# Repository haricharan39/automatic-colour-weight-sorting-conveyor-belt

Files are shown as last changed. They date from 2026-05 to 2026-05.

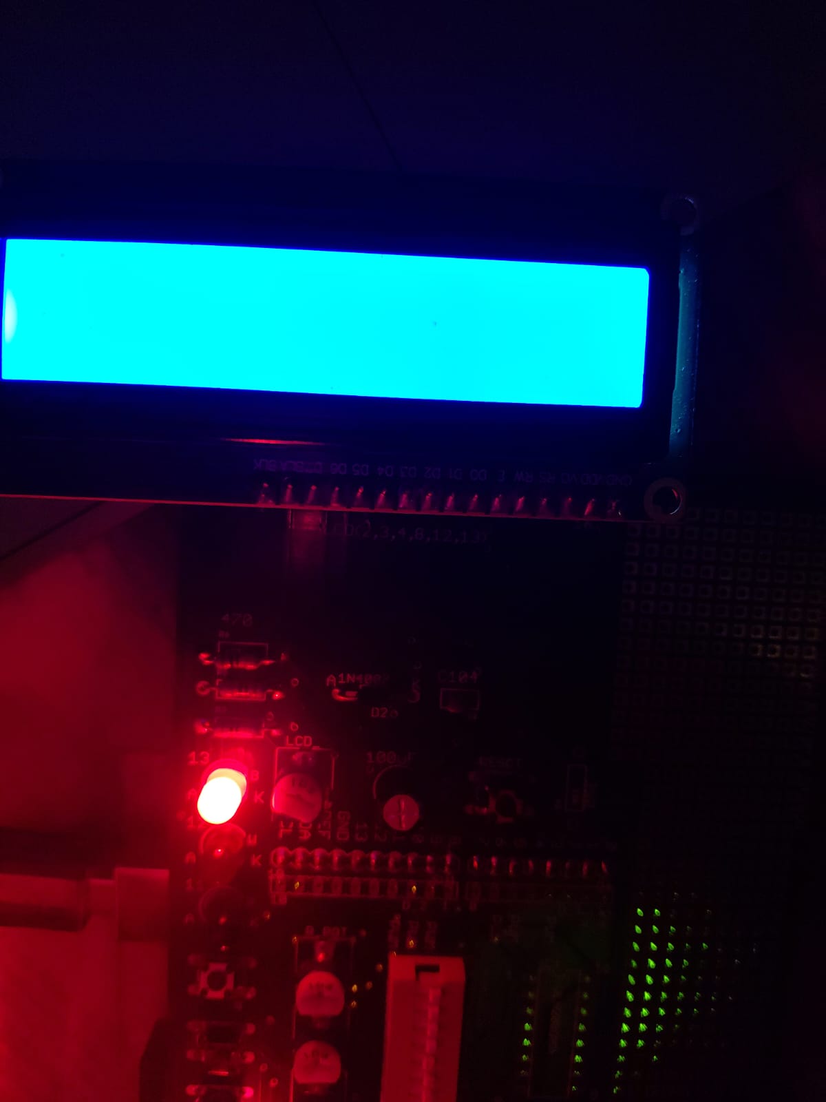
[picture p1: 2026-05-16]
Images/WhatsApp Image 2026-05-16 at 15.00.31.jpeg

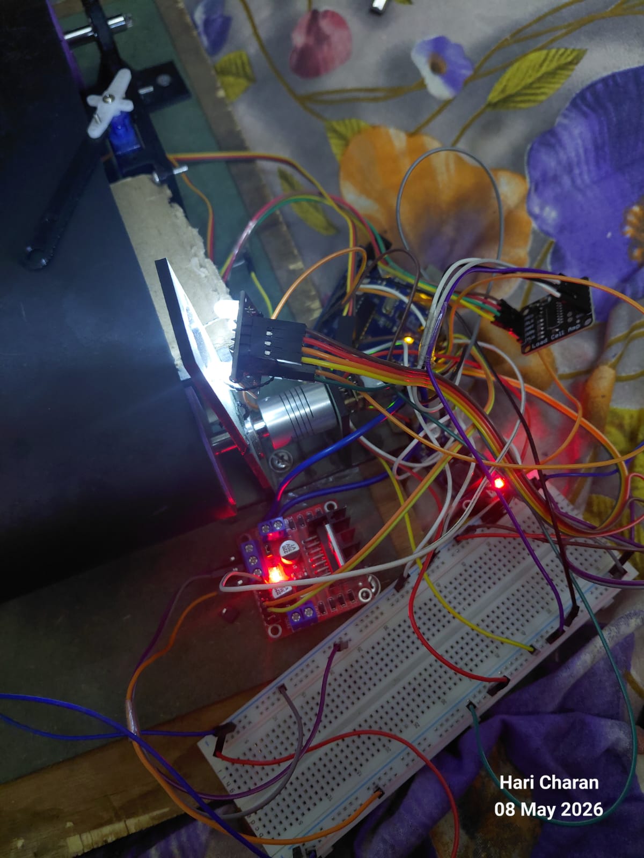
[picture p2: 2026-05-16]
Images/WhatsApp Image 2026-05-16 at 14.24.29 (3).jpeg

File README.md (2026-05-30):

# Automatic-Colour-Weight-Sorting-Conveyor-Belt

## Introduction

The Automatic Colour and Weight Sorting Conveyor Belt project is an Arduino-based automation system designed to identify and separate objects based on their colour and weight. The system uses sensors, a conveyor mechanism, and servo-controlled sorting techniques to automate the sorting process efficiently. This project demonstrates the practical application of automation, embedded systems, and sensor integration in industrial material handling and smart manufacturing systems.

## Objective

The objective of this project was to design and develop an automated conveyor belt system capable of sorting objects based on their colour and weight using sensors and microcontroller-based control systems. 

The project aimed to understand automation principles, sensor integration, object detection, and industrial sorting mechanisms through practical implementation.

## Components Used

* Arduino UNO
* Conveyor belt mechanism
* Servo motors
* Colour sensor
* Load cell sensor
* HX711 load cell amplifier
* IR sensors
* LCD display
* DC motor
* Motor driver module
* Power supply
* Connecting wires and supporting frame
* Cardboard
* Colours
* GI Sheets
* 3-D Printed Stuff

## Working Principle

The conveyor belt continuously moves objects through the sensing area. Firstly IR Detects the Object and the colour sensor detects the colour of the object, while the load cell measures its weight. The Arduino processes the sensor data and determines the appropriate category for the object.

Based on the detected parameters, servo motors are activated to divert the object into the correct collection section. The LCD display shows real-time information such as detected colour and measured weight during operation.

## Design and Implementation

The project was designed using a conveyor mechanism integrated with multiple sensors and servo-controlled sorting sections. The Arduino UNO acted as the main controller for processing sensor data and controlling the conveyor operation.

The load cell and colour sensor were calibrated carefully to improve measurement accuracy. Servo motors were positioned strategically to guide objects into separate sections based on predefined sorting conditions. The system was tested repeatedly to ensure smooth conveyor movement and accurate object classification.

## Engineering Concepts Applied

* Industrial automation
* Embedded systems
* Sensor integration
* Object detection and classification
* Conveyor mechanism design
* Control systems
* Microcontroller programming
* Mechatronics and automation

## Problems Faced

Several challenges were encountered during the development of the project. Sensor readings initially showed fluctuations and inconsistent values, affecting sorting accuracy. Conveyor movement also faced alignment and speed control issues during testing.

The servo motors occasionally responded with delays due to improper timing and synchronization with the conveyor system. Wiring management and sensor calibration required multiple adjustments to achieve stable operation.

## Solutions Implemented

Sensor calibration was performed multiple times to improve the accuracy and consistency of colour and weight detection. Noise reduction techniques and stable power connections helped minimize fluctuations in sensor readings.

The conveyor alignment was corrected to ensure smooth movement of objects without slipping or blockage. Motor speed adjustments were made to maintain proper synchronization between sensing and sorting operations.

Servo control timing was optimized in the Arduino program to achieve accurate object diversion at the correct moment. Wiring connections were organized carefully to improve reliability and reduce signal disturbances during operation and for load cell amplifier the soldering is not done efficiently so that the noise or voltage difference changes continuously so that the weight is not accurate and stable it is observed lately and corrected in no time....

## Testing and Results

The conveyor belt system was tested using objects with different colours and weights to evaluate sorting accuracy and system performance. During testing, the sensors successfully identified the object properties, and the servo motors sorted the objects into their respective sections.

The conveyor operated smoothly under continuous operation, and the overall system achieved reliable sorting performance with minimal errors. The project successfully demonstrated automated object detection, classification, and sorting using sensor-based control systems.

## Key Learnings

This project provided practical exposure to industrial automation systems and embedded control mechanisms. It improved understanding of sensor calibration, microcontroller programming, conveyor system design, and actuator control.

The project also demonstrated the importance of synchronization, accurate sensing, and system integration in automation-based applications. Valuable experience was gained in troubleshooting hardware issues, optimizing control logic, and improving system reliability through repeated testing.

## Future Improvements

The project can be improved further by integrating advanced sensors and machine vision systems for more accurate object detection and classification. Wireless monitoring and IoT-based control can also be implemented for remote operation and data analysis.

The conveyor system can be expanded to support higher-speed industrial applications with larger sorting capacities. Artificial intelligence and machine learning techniques may also be integrated in future versions to improve sorting accuracy and enable intelligent automation.

## Conclusion

The Automatic Colour and Weight Sorting Conveyor Belt project successfully demonstrated the implementation of automation and sensor-based sorting techniques using an Arduino-controlled system. The project achieved reliable object detection, classification, and sorting through the integration of sensors, actuators, and embedded programming.

The project provided valuable practical experience in automation, mechatronics, and industrial system design while highlighting the importance of precision, synchronization, and efficient control mechanisms in modern automated systems.

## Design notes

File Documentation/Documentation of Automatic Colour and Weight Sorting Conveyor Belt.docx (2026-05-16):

# Automated Conveyor Sorting System

# Introduction

Automation plays an important role in modern industries to increase efficiency and decrease manual effort. The conveyor system is used in most of the industries for transporting objects from one place to another. In some cases the objects need to be classified based on some characteristics such as colour or weight.

This project presents the design and development of a small automated conveyor system that detects the colour and weight of objects and sorts them into different bins. The system uses sensors and a microcontroller to perform the sorting operation automatically.

The goal of this project is to demonstrate the basic concept of industrial automation using simple Mechanical and electronic components.

# Objective

The main objective of project is to design and develop an Automated Conveyor Sorting System that can detect, analyze and sort objects based on their physical properties like colour and weight using sensors and microcontroller

This project aims to integrate various components like a colour sensor,load cell,IR sensor,DC motor and servo motors with an Arduino to create a real-time sorting mechanism.

↪️Specific Objectives

- To detect the presence of objects using an IR sensor
- To measure the weight of objects using a load cell with HX711 amplifier
- To identify the color of objects using a TCS3200 colour sensor
- To control conveyor movement using a DC motor and motor driver (L298N)
- To sort objects into different categories using servo motors
- To develop a complete system using Arduino UNO for control and processing

Components Used :

- Arduino UNO
- L298N Motor Driver
- Buck Converter (LM2596)
- DC Motor
- Servo Motors (2 units)
- IR Sensor
- TCS3200 Colour Sensor
- Load Cell
- HX711 Load Cell Amplifier
- Breadboard
- 12V Power Supply
- Connecting Wires
- 3D Printed Rollers
- Bearings
- Shaft Rod
- MDF Board
- Bread Board
- Rubber Sheet
- 3D Printed Servo Arms

WORKING PRINCIPLE

The automated conveyor sorting system operates by combining the functions of sensors, actuators, and a microcontroller to perform sorting of objects in a systematic manner.

Initially, the conveyor belt is driven by a DC motor, which provides continuous motion to transport objects from one end to another. When an object is placed on the moving conveyor belt, it starts traveling towards the sensing section of the system.

As the object reaches the sensing area, the IR sensor detects the presence of the object and sends a signal to the Arduino.

This detection ensures that the system begins analyzing the object at the correct position. Once the object is detected, the conveyor may momentarily slow down or continue moving steadily while the sensing process takes place.

The load cell placed beneath the sensing platform measures the weight of the object. The small electrical signal generated by the load cell is amplified and converted into digital data using the HX711 amplifier module, which is then read by the Arduino.

Simultaneously, the colour sensor (TCS3200) detects the color of the object by analyzing the light reflected from its surface. The sensor converts the color information into frequency signals, which are processed by the Arduino to determine the specific color of the object.

Based on the combined input from the weight measurement and color detection, the Arduino processes the data and classifies the object into a specific category. After classification, the conveyor continues to move the object towards the sorting section.

At the sorting point, the servo motor rotates its servo arm to a specific angle depending on the category of the object. This movement pushes the object into the appropriate bin or path assigned for that category.

This entire process is repeated continuously for every object placed on the conveyor belt, resulting in an efficient, accurate, and automated sorting system without the need for manual intervention.

Circuit Diagram

The circuit diagram of the automated conveyor sorting system is shown above. It illustrates the connections between the Arduino, sensors, motor driver, and power supply.

All components are connected through a common ground. The buck converter is used to provide a regulated 5V supply to the Arduino and sensors, while the motor driver is powered separately using a 12V supply.

The diagram clearly represents the interfacing of the colour sensor, IR sensor, load cell with HX711 module, servo motors, and DC motor with the Arduino.

Click Here (https://drive.google.com/file/d/1zyDLpXdCb_QY4AlogtuuWgVXAKq44nxD/view?usp=drivesdk) for the Circuit Diagram.

CONNECTIONS

The connections of the automated conveyor sorting system are made by interfacing all components with the Arduino and providing proper power supply through a buck converter and motor driver.

The 12V power supply is given to the L298N motor driver to drive the DC motor. The same 12V supply is also provided to the input of the buck converter.

The buck converter steps down the voltage to 5V, which is used to power the Arduino, sensors, and servo motors.

The DC motor is connected to the output terminals of the L298N motor driver. The control pins IN1 and IN2 of the motor driver are connected to the digital pins of the Arduino to control the direction of the motor.

The two servo motors are connected to the Arduino through digital pins, while their power is supplied from the 5V output of the buck converter. The IR sensor is connected to the Arduino to detect the presence of objects.

The colour sensor is connected to multiple digital pins of the Arduino for color detection, and its output pin is used to send frequency signals to the Arduino. The load cell is connected to the HX711 amplifier module, which is then connected to the Arduino for weight measurement.

All the ground connections of the components are made common to ensure proper functioning of the system.

DETAILED COMPONENT DESCRIPTION

↪️ Arduino UNO

- The Arduino UNO is the main controller of the system. It processes inputs from sensors and controls outputs like motors and servos.

Pins Used:

- 5V → Power input from buck converter
- GND → Common ground
- D2 → IR sensor output
- D3, D5 → L298N motor driver inputs
- D4, D6 → Servo motors
- D7–D10 → Colour sensor (S0–S3)
- D11 → Colour sensor OUT
- D12 → HX711 DT
- D13 → HX711 CLK

Use:

- Acts as the brain of the system.

↪️ L298N Motor Driver

- Used to control the DC motor and drive the conveyor.

Pins:

- 12V → Connected to 12V supply
- GND → Common ground
- 5V → Logic supply (from buck)
- IN1, IN2 → Connected to Arduino (D3, D5)
- OUT1, OUT2 → Connected to DC motor

Use:

- Controls motor direction and movement.

↪️ Buck Converter (LM2596)

- Used to step down voltage from 12V to 5V.

Pins:

- IN+ → 12V positive
- IN− → Ground
- OUT+ → 5V output
- OUT− → Ground

Use:

- Provides stable 5V to Arduino, sensors, and servos.

↪️ DC Motor

- Drives the conveyor belt.

Connection:

- Connected to OUT1 and OUT2 of L298N

Use:

- Moves objects on conveyor.

↪️Servo Motors (2)

- Used to sort objects.

Pins:

- Red → 5V
- Brown → GND
- Orange → Signal (D4, D6)

Use:

- Push objects into bins using a servo arm.

↪️ IR Sensor

- Detects presence of object.

Pins:

- VCC → 5V
- GND → GND
- OUT → Arduino D2

Use:

- Triggers detection when an object arrives.

↪️Colour Sensor (TCS3200)

Pins:

- VCC → 5V
- GND → GND
- S0 → D7
- S1 → D8
- S2 → D9
- S3 → D10
- OUT → D11
- OE → GND

Use:

- Detects color of object.

↪️ Load Cell

Wires:

- Red → E+
- Black → E−
- Green → A+
- White → A−

Use:

- Measures weight of object.

↪️ HX711 Amplifier

Pins:

- VCC / VDD → 5V
- GND → GND
- DT → D12
- CLK → D13
- A+, A− → Load cell
- E+, E− → Load cell

Use:

- Amplifies and converts load cell signal.

↪️ Breadboard

Use:

- Distributes 5V and GND
- Organizes connections

Connection:

- Buck OUT+ → 5V rail
- Buck OUT− → GND rail

↪️ Power Supply (12V)

Connection:

- 12V → L298N motor driver
- 12V → Buck converter input

Use:

- Provides main power for the system.

APPLICATIONS

- Industrial product sorting systems
- Packaging and assembly lines
- Waste segregation systems
- Food processing industries
- Recycling plants
- Smart manufacturing systems

Problems Faced During the Project

1. Unstable Load Cell Readings

One of the major challenges faced during the project. was obtaining stable and accurate readings from the load cell. Since the load cell produces very small analog signals, the readings were highly sensitive to vibrations, electrical noise, and loose wiring connections. Initially, the measured values fluctuated continuously and sometimes displayed zero even when weight was applied. This issue became more noticeable when the conveyor motor and servo motors were operating simultaneously.

To reduce this problem, multiple software filtering techniques such as averaging and stabilization delays were implemented. The HX711 module was also powered using 3.3V instead of 5V to reduce electrical noise. Additionally, the wiring connections were improved and secured properly.

2. Electrical Noise from Motor and Servos

The DC motor and servo motors generated electrical noise and electromagnetic interference (EMI), which affected the HX711 load cell amplifier. Whenever the conveyor motor stopped or the servos moved, unstable weight readings were observed. The noise also caused sudden fluctuations in sensor outputs.

To overcome this issue, delay intervals were introduced after stopping the motor so that vibrations and electrical disturbances could settle before taking weight measurements. Servo motors were also detached after movement to minimize PWM interference during weight sensing.

3. Incorrect Color Detection

The TCS3200 color sensor initially produced inconsistent color outputs. In several cases, the sensor repeatedly detected the same color even when different colored objects were placed in front of it. Environmental lighting conditions and improper sensor distance also affected the readings.

To improve color detection accuracy, multiple pulse readings were averaged and threshold comparisons were adjusted experimentally. Proper object placement and controlled lighting conditions helped achieve more reliable RGB detection.

4. Servo Motor Stability Issues

The SG90 servo motors did not hold angles firmly and occasionally showed jittering or shaking movements. This mainly occurred due to insufficient power supply and continuous PWM corrections by the servos. The shaking affected the sorting mechanism and caused inaccurate object sweeping.

Instead of using a locking mechanism, a sweeping mechanism was designed in which the servo quickly pushes the object into the required bin and returns to its home position. This reduced the load on the servos and improved overall reliability.

5. Conveyor Belt Alignment Problems

Maintaining proper conveyor belt alignment was another challenge during the mechanical assembly. Improper roller alignment caused uneven belt movement and occasional slipping of objects during transportation. The belt tension also had to be adjusted carefully to ensure smooth operation.

To solve this issue, roller supports and shaft supporters were redesigned and aligned properly. The mechanical structure was strengthened to improve stability during continuous operation.

6. Integration of Multiple Components

Integrating all hardware components into one synchronized system was a challenging task. Individual modules such as the load cell, color sensor, servo motors, and LCD worked correctly when tested separately, but issues appeared when all modules operated together simultaneously.

Careful timing control, sequencing of operations, and debugging were required to achieve stable integration. Delays were introduced between sensing and actuation stages to ensure proper synchronization between hardware and software operations.

7. Calibration Difficulties

The calibration factor of the load cell changed after modifying the power supply configuration and integrating the system with other components. Accurate weight measurement required repeated calibration trials using known weights.

Several experimental tests were conducted to determine a suitable calibration factor and weight threshold for differentiating HIGH and LOW weight objects accurately.

8. Timing and Synchronization Challenges

Proper coordination between conveyor movement, IR detection, color sensing, weight measurement, and servo actuation was critical for smooth operation. Incorrect timing caused premature sensing or inaccurate sorting.

To solve this issue, the complete workflow was redesigned with proper sequencing:

1. Conveyor motor runs
2. IR sensor detects object
3. Motor stops
4. Object stabilizes
5. Color and weight are measured
6. Servo performs sorting action

CONCLUSION

The automated conveyor sorting system successfully demonstrates the integration of sensors, actuators, and a microcontroller to perform sorting operations efficiently. The system is capable of detecting objects, analyzing their weight and color, and sorting them automatically without manual intervention.

This project highlights the practical application of embedded systems in automation and industrial processes. It can be further improved by increasing accuracy, adding more sensors, or implementing advanced control techniques.

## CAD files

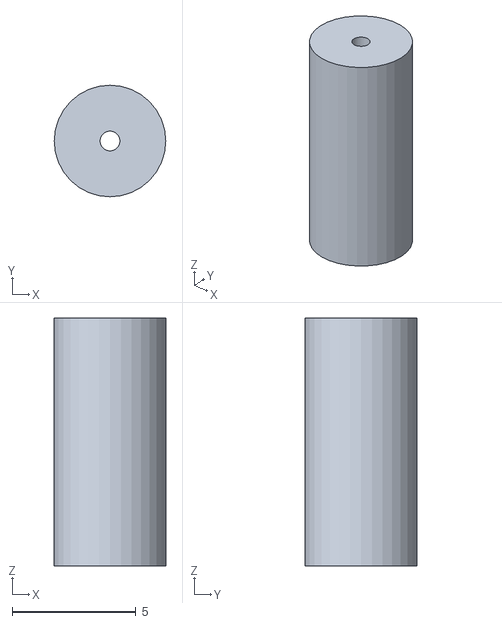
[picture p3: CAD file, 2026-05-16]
AutoCad Design/Roller.stl
4.50 x 4.50 x 10.0

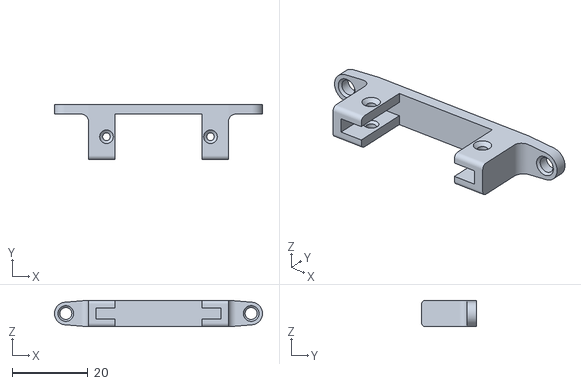
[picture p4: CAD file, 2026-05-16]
AutoCad Design/Servo Mounter.stl
55.0 x 14.5 x 7.00

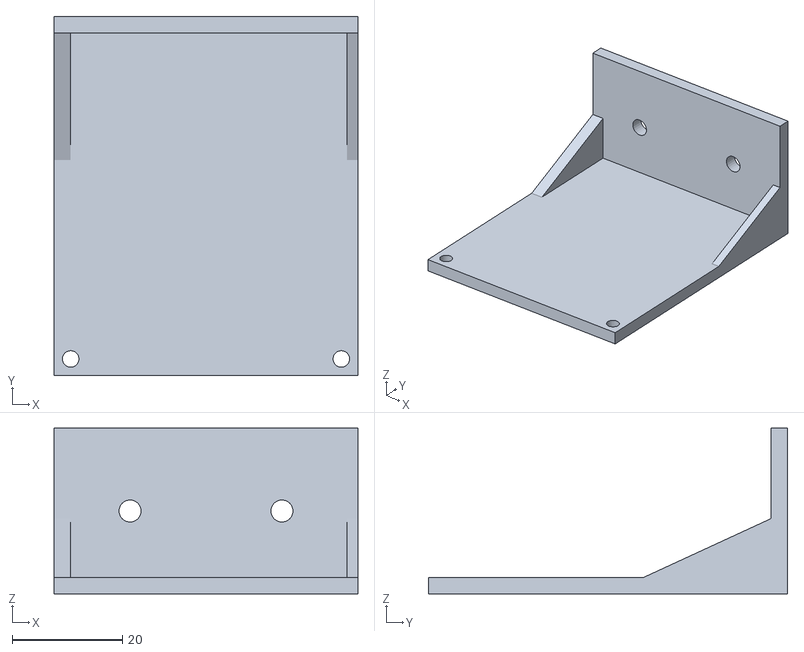
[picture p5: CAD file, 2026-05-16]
AutoCad Design/Servo Bracket.stl
55.0 x 65.0 x 30.0

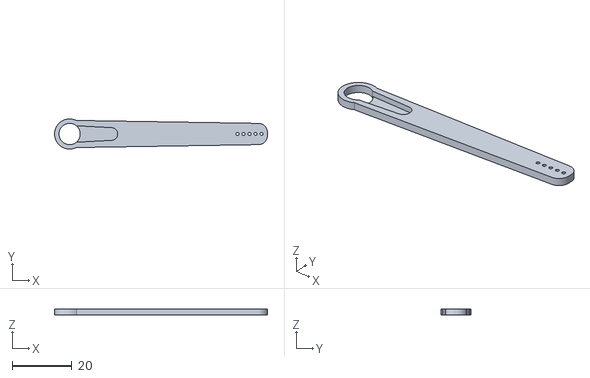
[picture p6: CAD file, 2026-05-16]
AutoCad Design/Servo Paddle.STL
71.1 x 10.1 x 2.00

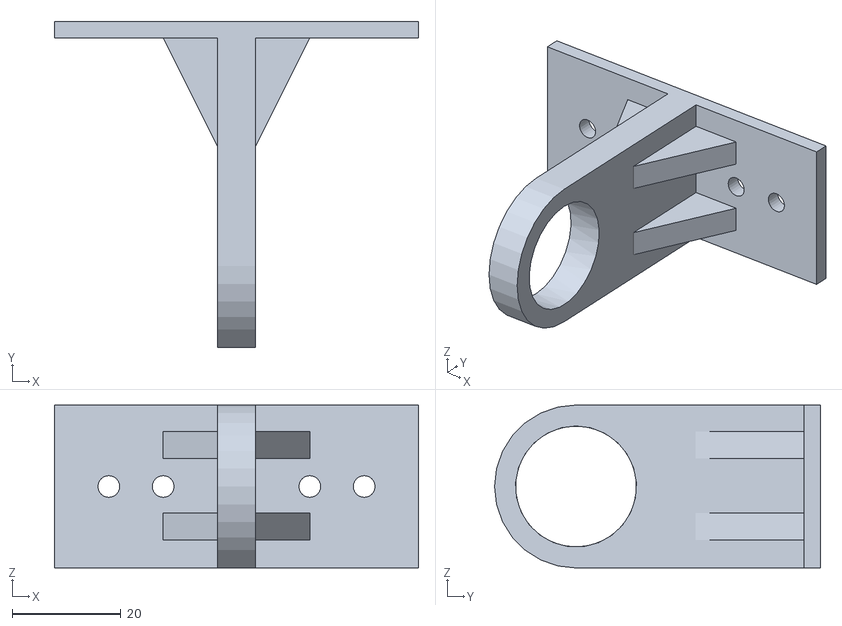
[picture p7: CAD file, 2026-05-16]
AutoCad Design/L-brackets supporter.stl
67.0 x 60.0 x 30.0

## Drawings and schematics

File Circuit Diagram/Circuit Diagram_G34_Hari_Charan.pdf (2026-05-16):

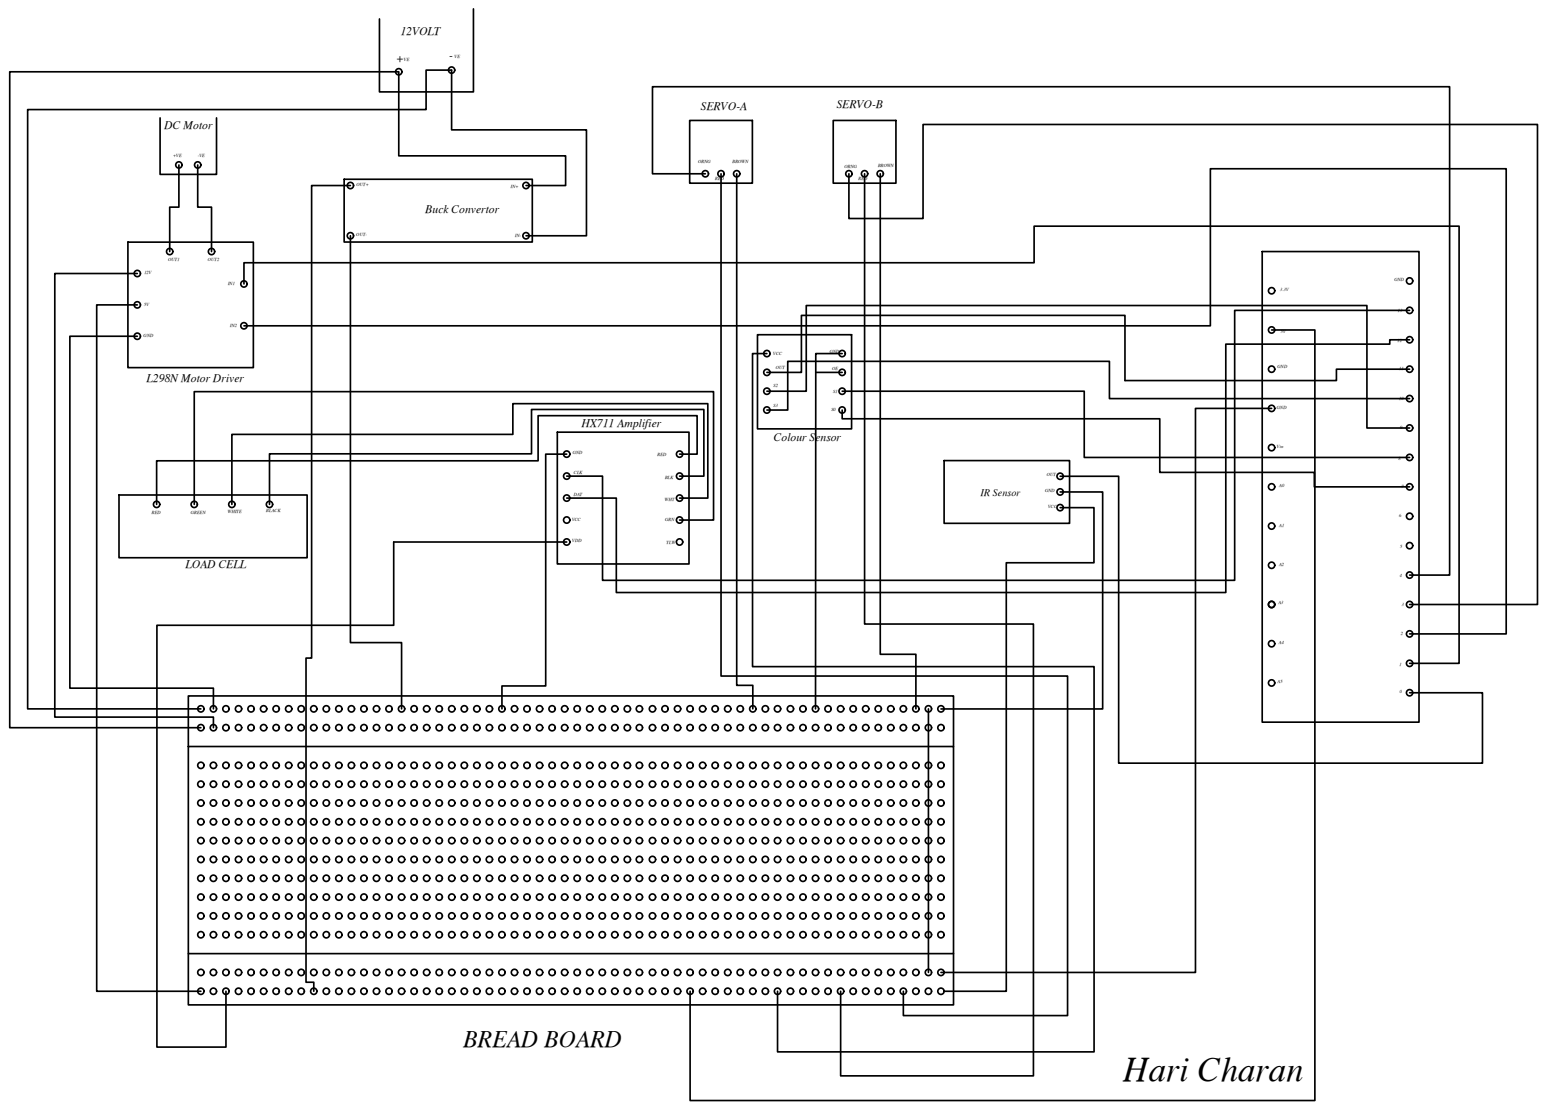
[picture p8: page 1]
Buck Convertor; Colour Sensor HX711 Amplifier L298N Motor Driver DC Motor; IR Sensor LOAD CELL; BREAD BOARD; SERVO-A; SERVO-B +; - 12VOLT; IN+IN- OUT+ OUT- 12V 5VGND; IN1IN2 OUT1; OUT2 RED; GREEN; WHITE; BLACK; GND CLK DAT VCC VDD; REDBLK WHT GRN YLW; VCCOUT S2S3; S0S1 OE GND; OUT GNDVCC ORNG RED; BROWN; RED ORNG; BROWN +VE; 01234567891011 1213 GND 3.3V 5V GND GND VinA0A1 A2 A3A4 A5 Hari Charan

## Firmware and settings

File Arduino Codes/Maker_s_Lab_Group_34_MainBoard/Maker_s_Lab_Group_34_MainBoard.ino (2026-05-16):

#include <Servo.h>
#include "HX711.h"
#define DOUT_PIN      3
#define CLK_PIN       2
#define S0_PIN        4
#define S1_PIN        5
#define S2_PIN        6
#define S3_PIN        7
#define COLOR_OUT_PIN 8
#define IR_PIN        9
#define ENA_PIN       10
#define IN1_PIN       12
#define IN2_PIN       11
#define SERVO_A_PIN   A0
#define SERVO_B_PIN   A1
const float FACTOR       = 1837.5;
const float WEIGHT_HIGH  = 36;
const float NOISE_FLOOR  = 3.0;
const int   MOTOR_SPEED  = 255;
const long  IR_TIMEOUT   = 45000;
const int  COLOR_GAP     = 20;
const long PULSE_TIMEOUT = 200000;
HX711 scale;
Servo servoA;
Servo servoB;
float finalWeight   = 0.0;
byte  detectedColor = 0;
void sendWaiting() {
  Serial.println(F("STATUS:WAIT"));
}
void sendReady() {
  Serial.println(F("STATUS:READY"));
}
void sendToDisplay(float weight, byte color) {
  String wLabel = (weight >= WEIGHT_HIGH) ? "HIGH" : "LOW";
  String cLabel;
  if      (color == 1) cLabel = "Red";
  else if (color == 3) cLabel = "Blue";
  else                 cLabel = "Unknown";
  Serial.print(F("W:"));
  Serial.print(wLabel);
  Serial.print(F(",C:"));
  Serial.println(cLabel);
}
void setup() {
  Serial.begin(9600);
  pinMode(ENA_PIN, OUTPUT);
  pinMode(IN1_PIN, OUTPUT);
  pinMode(IN2_PIN, OUTPUT);
  digitalWrite(IN1_PIN, LOW);
  digitalWrite(IN2_PIN, LOW);
  analogWrite(ENA_PIN, 0);
  pinMode(IR_PIN, INPUT);
  pinMode(S0_PIN, OUTPUT);
  pinMode(S1_PIN, OUTPUT);
  pinMode(S2_PIN, OUTPUT);
  pinMode(S3_PIN, OUTPUT);
  pinMode(COLOR_OUT_PIN, INPUT);
  digitalWrite(S0_PIN, HIGH);
  digitalWrite(S1_PIN, LOW);
  digitalWrite(S2_PIN, LOW);
  digitalWrite(S3_PIN, LOW);
  servoA.attach(SERVO_A_PIN);
  servoB.attach(SERVO_B_PIN);
  servoA.write(0);
  servoB.write(0);
  delay(800);
  servoA.detach();
  servoB.detach();
  scale.begin(DOUT_PIN, CLK_PIN);
  delay(500);
  scale.set_scale(FACTOR);
  scale.power_up();
  scale.tare();
  delay(300);
}
void startMotor() {
  digitalWrite(IN1_PIN, HIGH);
  digitalWrite(IN2_PIN, LOW);
  analogWrite(ENA_PIN, MOTOR_SPEED);
}
void stopMotor() {
  digitalWrite(IN1_PIN, HIGH);
  digitalWrite(IN2_PIN, HIGH);
  analogWrite(ENA_PIN, 0);
  delay(150);
  digitalWrite(IN1_PIN, LOW);
  digitalWrite(IN2_PIN, LOW);
  delay(2000);
}
byte detectColor() {
  long redPulse;
  long greenPulse;
  long bluePulse;
  digitalWrite(S2_PIN, LOW);
  digitalWrite(S3_PIN, LOW);
  delay(50);
  redPulse = pulseIn(COLOR_OUT_PIN, LOW, PULSE_TIMEOUT);
  digitalWrite(S2_PIN, HIGH);
  digitalWrite(S3_PIN, HIGH);
  delay(50);
  greenPulse = pulseIn(COLOR_OUT_PIN, LOW, PULSE_TIMEOUT);
  digitalWrite(S2_PIN, LOW);
  digitalWrite(S3_PIN, HIGH);
  delay(50);
  bluePulse = pulseIn(COLOR_OUT_PIN, LOW, PULSE_TIMEOUT);
  if (redPulse == 0 && greenPulse == 0 && bluePulse == 0) {
    return 0;
  }
  if (redPulse == 0)   redPulse   = 999999L;
  if (greenPulse == 0) greenPulse = 999999L;
  if (bluePulse == 0)  bluePulse  = 999999L;
  if (redPulse < greenPulse && redPulse < bluePulse) {
    if ((min(greenPulse, bluePulse) - redPulse) > COLOR_GAP) {
      return 1;
    }
  }
  if (greenPulse < redPulse && greenPulse < bluePulse) {
    if ((min(redPulse, bluePulse) - greenPulse) > COLOR_GAP) {
      return 2;
    }
  }
  if (bluePulse < redPulse && bluePulse < greenPulse) {
    if ((min(redPulse, greenPulse) - bluePulse) > COLOR_GAP) {
      return 3;
    }
  }
  return 0;
}
float readWeight() {
  delay(400);
  scale.power_up();
  delay(800);
  float avg = 0;
  for (int i = 0; i < 10; i++) {
    avg += scale.get_units(5);
    delay(50);
  }
  float reading = avg / 10.0;
  if (reading < 0) {
    reading = 0;
  }
  if (reading < NOISE_FLOOR) {
    reading = 0;
  }
  Serial.println(reading);
  return reading;
}
void moveServos(int a, int b) {
  servoA.attach(SERVO_A_PIN);
  servoB.attach(SERVO_B_PIN);
  servoA.write(a);
  servoB.write(b);
  delay(1200);
}
void sweepServoA(int fromAngle, int toAngle, int stepDelay) {
  servoA.attach(SERVO_A_PIN);
  int step = (toAngle > fromAngle) ? 1 : -1;
  for (int pos = fromAngle; pos != toAngle; pos += step) {
    servoA.write(pos);
    delay(stepDelay);
  }
  servoA.write(toAngle);
}
void sweepServoB(int fromAngle, int toAngle, int stepDelay) {
  servoB.attach(SERVO_B_PIN);
  int step = (toAngle > fromAngle) ? 1 : -1;
  for (int pos = fromAngle; pos != toAngle; pos += step) {
    servoB.write(pos);
    delay(stepDelay);
  }
  servoB.write(toAngle);
}
void resetServos() {
  servoA.write(0);
  servoB.write(0);
  delay(600);
  servoA.detach();
  servoB.detach();
}
bool sortObject(byte color, float weight) {
  bool high = (weight >= WEIGHT_HIGH);
  if (!high) {
    if (color == 1) {
      startMotor();
      servoA.attach(SERVO_A_PIN);
      servoA.write(90);
      delay(400);
      sweepServoA(140, 0, 25);
      delay(400);
      return true;
    }
    else if (color == 3) {
      moveServos(140, 0);
      startMotor();
    }
  }
  else {
    if (color == 1) {

      moveServos(0, 42);
    }
    else if (color == 3) {
    }
  }
  return false;
}
void loop() {
  sendReady();
  startMotor();
  unsigned long t = millis();
  while (digitalRead(IR_PIN) == HIGH) {
    delay(750);

    if (millis() - t > IR_TIMEOUT) {

      stopMotor();

      return;
    }
  }
  stopMotor();
  delay(3000);
  sendWaiting();
  detectedColor = detectColor();
  finalWeight = readWeight();
  sendToDisplay(finalWeight, detectedColor);
  bool beltAlreadyOn = sortObject(detectedColor, finalWeight);
  if (!beltAlreadyOn) {

    startMotor();
  }
  delay(5000);
  resetServos();
  delay(800);
  stopMotor();
  delay(300);
  scale.power_up();
  delay(500);
  scale.tare();
  delay(1000);
}

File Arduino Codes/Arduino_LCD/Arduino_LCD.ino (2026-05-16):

#include <LiquidCrystal.h>
LiquidCrystal lcd(2, 3, 4, 8, 12, 13);
String incoming = "";
void setup() {
  Serial.begin(9600);
  lcd.begin(16, 2);
  lcd.clear();
  lcd.setCursor(0, 0);
  lcd.print("Waiting...");
}
void loop() {
  while (Serial.available()) {
    char c = Serial.read();

    if (c == '\n') {
      processMessage(incoming);
      incoming = "";
    } else if (c != '\r') {
      incoming += c;
    }
  }
}
void processMessage(String msg) {
  msg.trim();
  if (msg == "STATUS:READY") {
    lcd.clear();
    lcd.setCursor(0, 0);
    lcd.print("System Ready");
    return;
  }
  if (msg == "STATUS:WAIT") {
    lcd.clear();
    lcd.setCursor(0, 0);
    lcd.print("Scanning...");
    return;
  }
  int wStart = msg.indexOf("W:") + 2;
  int wEnd   = msg.indexOf(",C:");
  int cStart = msg.indexOf(",C:") + 3;
  if (wStart < 2 || wEnd < 0 || cStart < 3) {
    lcd.clear();
    lcd.setCursor(0, 0);
    lcd.print("Parse error");
    return;
  }
  String wLabel = msg.substring(wStart, wEnd);
  String cLabel = msg.substring(cStart);
  wLabel.trim();
  cLabel.trim();
  lcd.clear();
  lcd.setCursor(0, 0);
  lcd.print("Wt: ");
  lcd.print(wLabel);
  lcd.setCursor(0, 1);
  lcd.print("Color: ");
  lcd.print(cLabel);
}

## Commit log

2026-05-16 Added automatic colour and weight sorting conveyor belt project
    [L-brackets supporter.stl, Roller.stl, Servo Bracket.stl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]
2026-05-16 Added Arduino code files
